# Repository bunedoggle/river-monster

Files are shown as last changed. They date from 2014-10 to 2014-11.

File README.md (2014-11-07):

river-monster
=============

River monitoring hack-a-thon at the Lowell Makerspace.

Goals:
 - Battery-less sensors using energy havevesting
 - Sensor gateway using SMS
 - Solar gateway charging

###Update: 11/6/2014

As a first pass project we're going to change the remote sensor design.  Each sensor node will use an inexpensive 433Mhz transmitter module (like this) and an Arduino pro mini.  Using the low power library we shuold be able to get month of battery life from a few AA batteries, maybe longer with a lithium-ion.

The gateway will be an Arduino Uno with a GPRS sheild, 433 Mhz reciever and a large antenna.

This will greatly simplify the design and allow us to quickly build a proof on concept that can be expanded.

See the wiki for more info. 

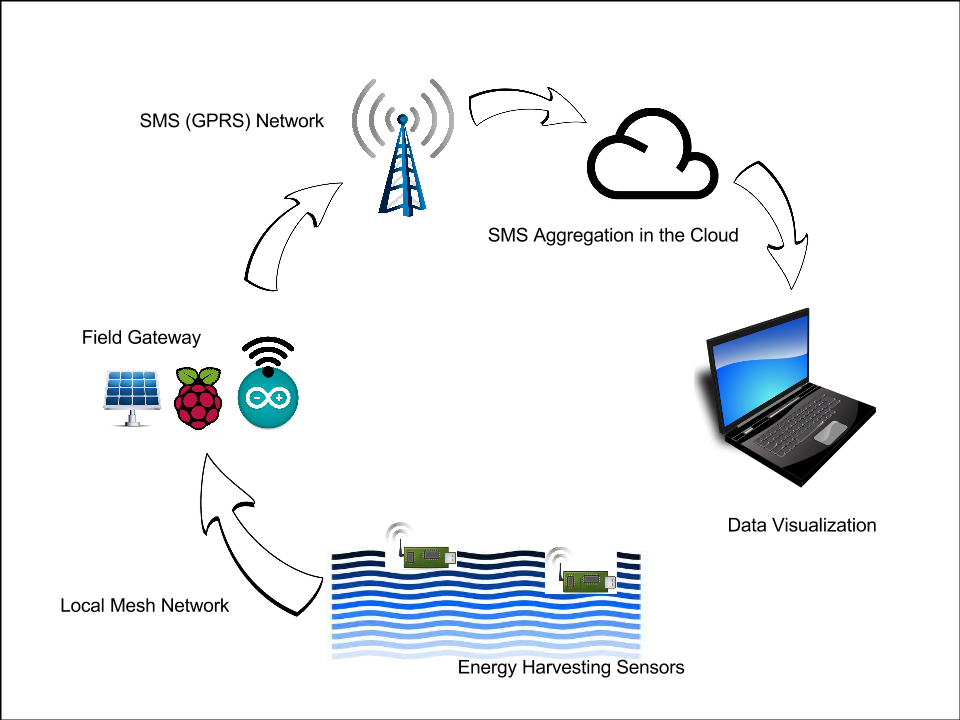
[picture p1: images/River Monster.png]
River monster block diagram


Resources:
 - http://www.seeedstudio.com/depot/GPRS-Shield-V20-p-1379.html?cPath=132_134
 - http://publiclab.org/wiki/water-quality-sensor
 - https://www.enocean.com/en/enocean-pi/

Low Power Arduino lib:
 - http://www.rocketscream.com/blog/2011/07/04/lightweight-low-power-arduino-library/
 - https://github.com/rocketscream/Low-Power

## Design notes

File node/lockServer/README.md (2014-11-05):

DEPLOYMENT

- Install node.js and MongoDB (figure it out!)

- You must have a Twilio acccount for this application to work.
  - Sign up at Twilio and obtain a phone number

- You also need a publicly accessible server for Twilio to callback to when SMS arrives
  - see ngrok.com for a way to expose localhost externally

- Login to Twilio and redirect the callback page to http://<yourserver>/api/smsMessage

There is a version currently hosted on OpenShift.  This project has all the crap
needed to make that work (they use environment vars to figure out the right
ports and address to use.  It will work locally or on OpenShift).

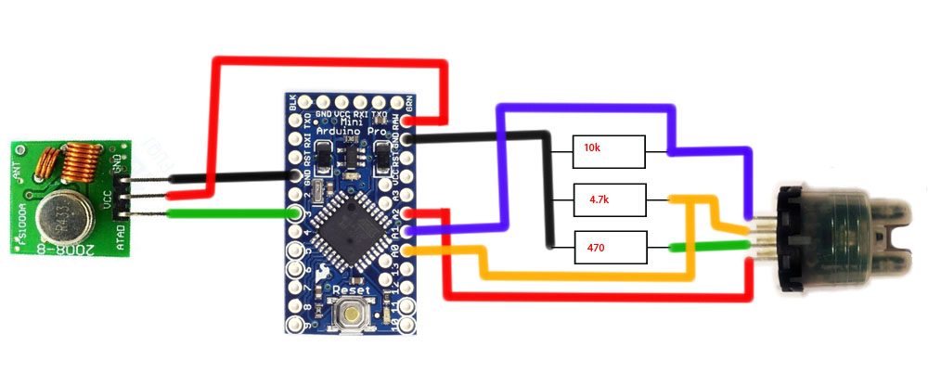
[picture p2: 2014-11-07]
images/sensor_node_rev1.jpg

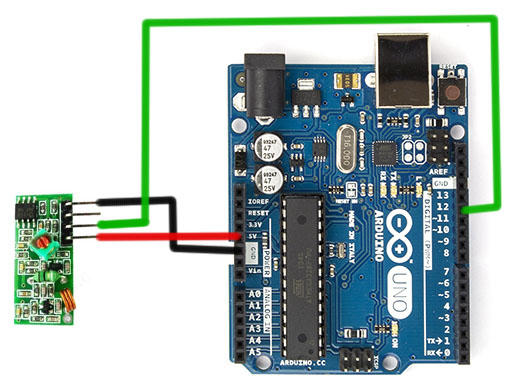
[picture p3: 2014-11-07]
images/gateway_rev1.jpg

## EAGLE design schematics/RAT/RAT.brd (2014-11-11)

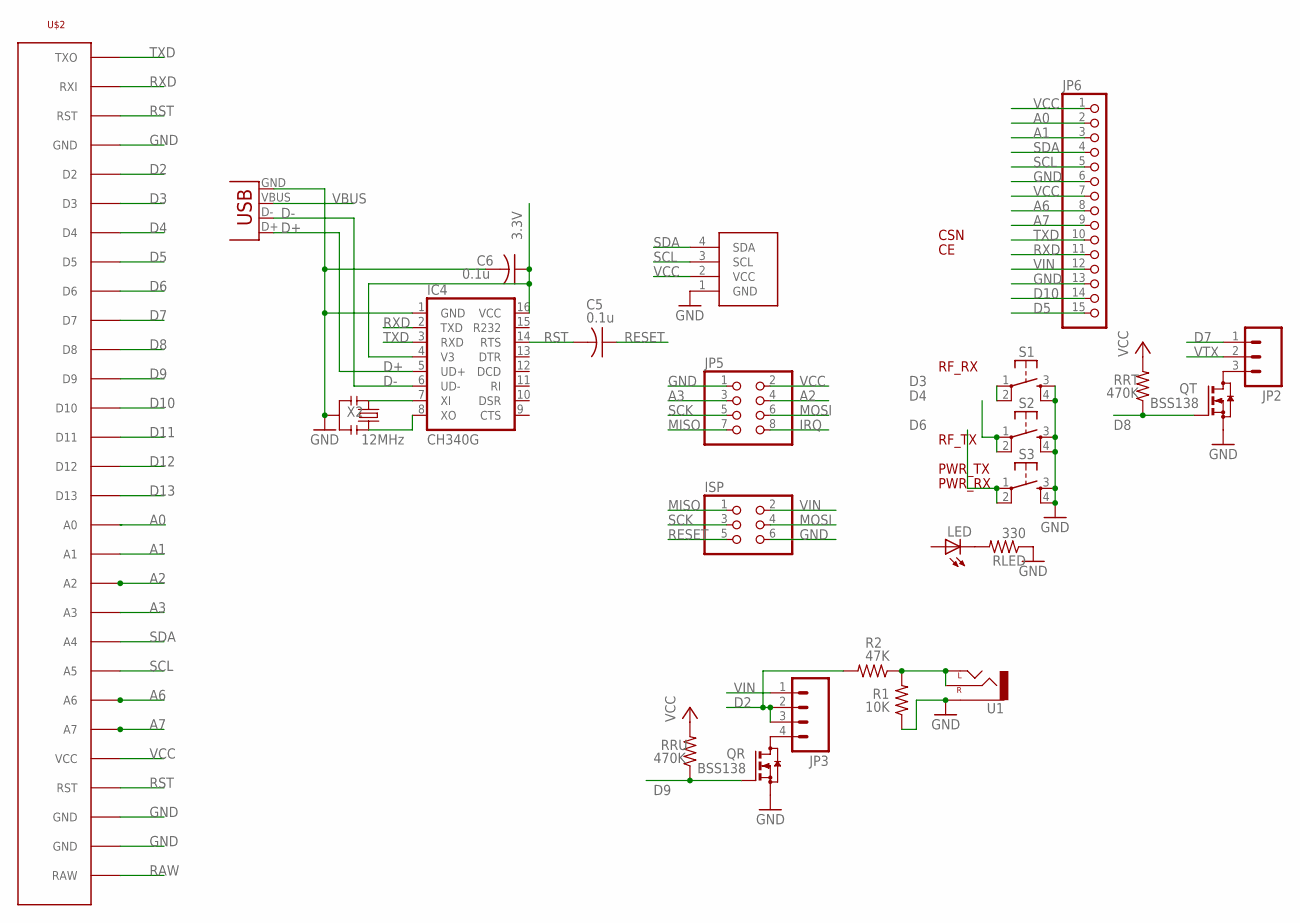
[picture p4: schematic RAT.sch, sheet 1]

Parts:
C5, C6: 0.1u; C0805K
IC4: CH340G; SO16
ISP: PINHD-2X3; 2X03
JP2: M03LOCK_LONGPADS; 1X03_LOCK_LONGPADS
JP3: M04LOCK; 1X04_LOCK
JP5: PINHD-2X4; 2X04
JP6: PINHD-1X15-CB; 1X15-CB
LED: LEDCHIPLED_0805; CHIPLED_0805
QR: BSS138; SOT23
QT: BSS138; SOT23
R1: 10K; R0805
R2: 47K; R0805
RLED: 330; R0805
RRT: 470K; R0805
RRU: 470K; R0805
S1, S2, S3: TAC_SWITCHPTH; TACTILE-PTH
U1: AUDIO-JACKPTH; AUDIO-JACK
U$1: SSD1306_OLED_I2C
U$2: ARDUINO-PRO-MINI-CORRECT; ARDUINO-PRO-MINI
X1: USBSMD; USB-MINIB
X2: 12MHz; RESONATOR-SMD

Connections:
3.3V: C6.1, IC4.4 (V3), IC4.16 (VCC)
A0: JP6.2, U$2.A0
A1: JP6.3, U$2.A1
A2: JP5.4, U$2.A2
A3: JP5.3, U$2.A3
A6: JP6.8, U$2.A6@1 (A6), U$2.A6@2 (A6)
A7: JP6.9, U$2.A7@1 (A7), U$2.A7@2 (A7)
D2: JP3.2, JP3.3, R2.2, U$2.2 (D2)
D3: S1.1, S1.2, U$2.3 (D3)
D4: S2.1, S2.2, U$2.4 (D4)
D5: JP6.15, U$2.5 (D5)
D6: S3.1, S3.2, U$2.6 (D6)
D7: JP2.1, U$2.7 (D7)
D8: QT.1 (G), RRT.1, U$2.8 (D8)
D9: QR.1 (G), RRU.1, U$2.9 (D9)
D10: JP6.14, U$2.10 (D10)
D11: U$2.11 (D11)
D12: U$2.12 (D12)
D13: U$2.13 (D13)
D+: IC4.5 (UD+), X1.D+
D-: IC4.6 (UD-), X1.D-
GND: C6.2, IC4.1 (GND), ISP.6, JP5.1, JP6.6, JP6.13, QR.2 (S), QT.2 (S), R1.1, RLED.1, S1.3, S1.4, S2.3, S2.4, S3.3, S3.4, U1.SLEEVE, U$1.1 (GND), U$2.GND@1 (GND), U$2.GND@2 (GND), U$2.GND@3 (GND), X1.GND, X2.2; also elsewhere on the board
IRQ: JP5.8
MISO: ISP.1, JP5.7
MOSI: ISP.4, JP5.6
unnamed: LED.C, RLED.2
unnamed: R1.2, R2.1, U1.RING (RIGHT), U1.TIP (LEFT)
unnamed: JP3.4, QR.3 (D)
unnamed: JP2.3, QT.3 (D)
unnamed: IC4.7 (XI), X2.1
unnamed: IC4.8 (XO), X2.3
RAW: U$2.RAW
RESET: C5.1, ISP.5
RST: C5.2, IC4.14 (RTS), U$2.RST@1 (RST), U$2.RST@2 (RST)
RXD: IC4.2 (TXD), JP6.11, U$2.RXI
SCK: ISP.3, JP5.5
SCL: JP6.5, U$1.3 (SCL), U$2.A5
SDA: JP6.4, U$1.4 (SDA), U$2.A4
TXD: IC4.3 (RXD), JP6.10, U$2.TXO
VBUS: X1.VBUS; also elsewhere on the board
VCC: JP5.2, JP6.1, JP6.7, RRT.2, RRU.2, U$1.2 (VCC), U$2.VCC; also elsewhere on the board
VIN: ISP.2, JP3.1, JP6.12
VTX: JP2.2; also elsewhere on the board

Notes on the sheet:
RF_RX
PWR_RX
PWR_TX
RF_TX
CSN

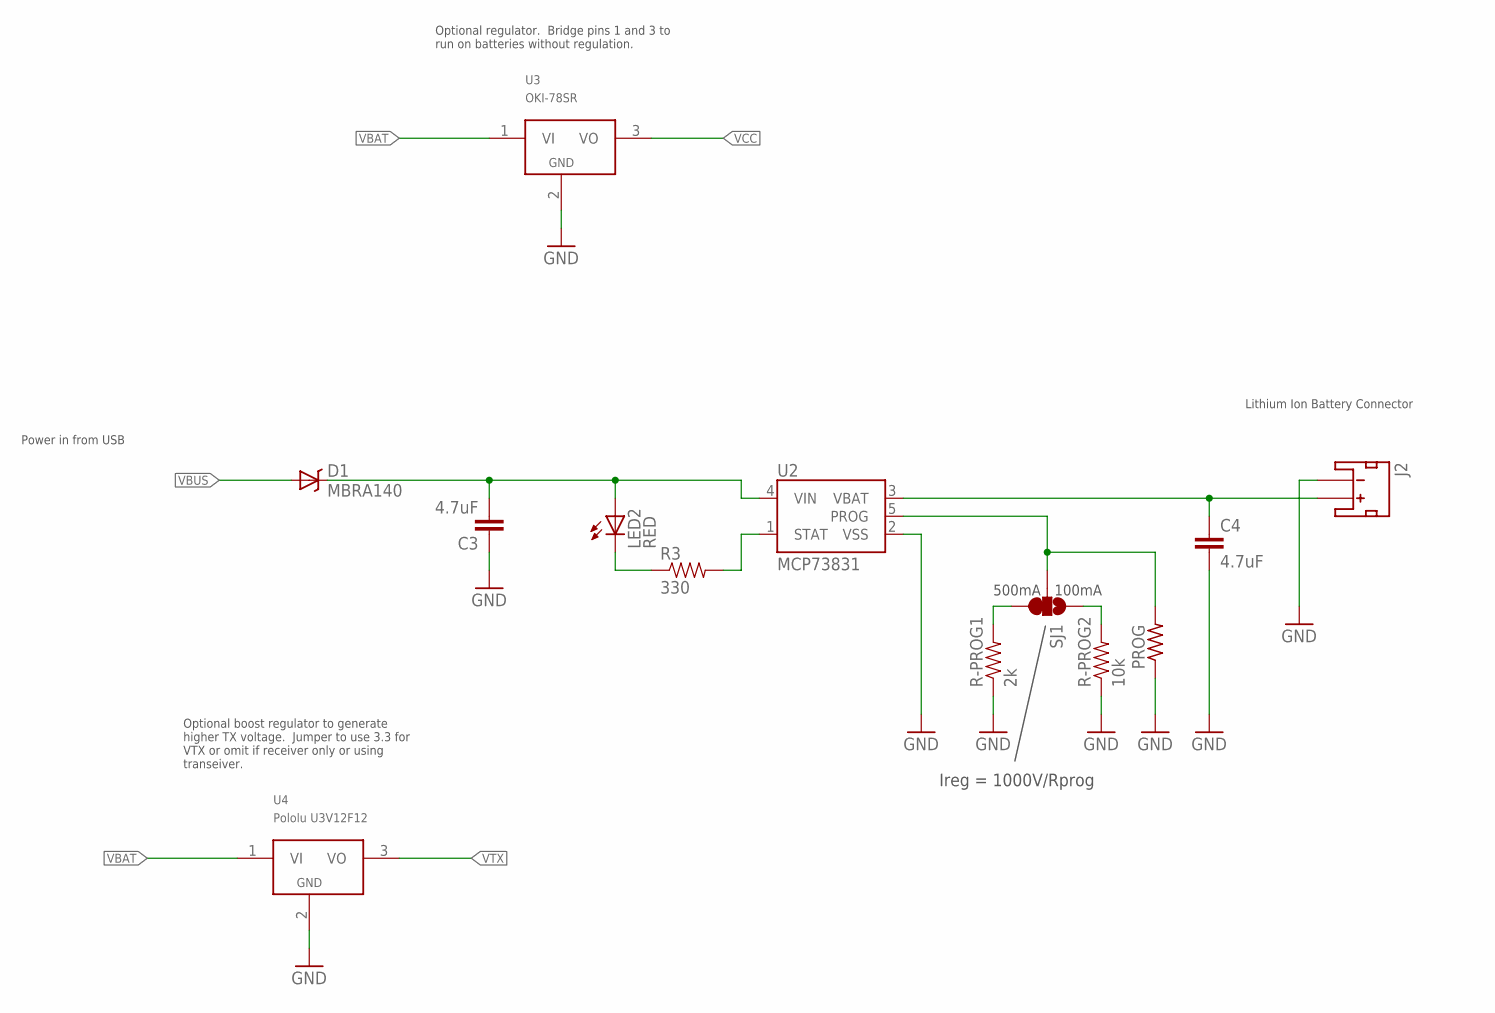
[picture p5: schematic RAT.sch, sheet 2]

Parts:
C3, C4: 4.7uF; 0603-CAP
D1: MBRA140; SMA-DIODE
J2: JST_2MM_MALE; JST-2-SMD
LED2: RED; LED-0603
PROG: R-US_R0603; R0603
R3: 330; 0603-RES
R-PROG1: 2k; 0603-RES
R-PROG2: 10k; 0603-RES
SJ1: SOLDERJUMPER_2WAYS; SJ_3
U2: MCP73831; SOT23-5
U3: OKI-78SR; TO-220
U4: Pololu U3V12F12; TO-220

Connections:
GND: C3.1, C4.2, J2.1 (-), PROG.1, R-PROG1.1, R-PROG2.1, U2.2 (VSS), U3.2 (GND), U4.2 (GND); also elsewhere on the board
unnamed: R-PROG1.2, SJ1.3
unnamed: R3.2, U2.1 (STAT)
unnamed: R-PROG2.2, SJ1.1
unnamed: LED2.C, R3.1
PROG: PROG.2, SJ1.2, U2.5 (PROG)
VBAT: C4.1, J2.2 (+), U2.3 (VBAT), U3.1 (VI), U4.1 (VI)
VBUS: D1.A; also elsewhere on the board
VBUS_DIODE: C3.2, D1.C, LED2.A, U2.4 (VIN)
VCC: U3.3 (VO); also elsewhere on the board
VTX: U4.3 (VO); also elsewhere on the board

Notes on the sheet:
500mA
100mA
Ireg = 1000V/Rprog
Optional regulator. Bridge pins 1 and 3 to run on batteries without regulation.
Lithium Ion Battery Connector
Power in from USB
Optional boost regulator to generate higher TX voltage. Jumper to use 3.3 for VTX or omit if receiver only or using transeiver.

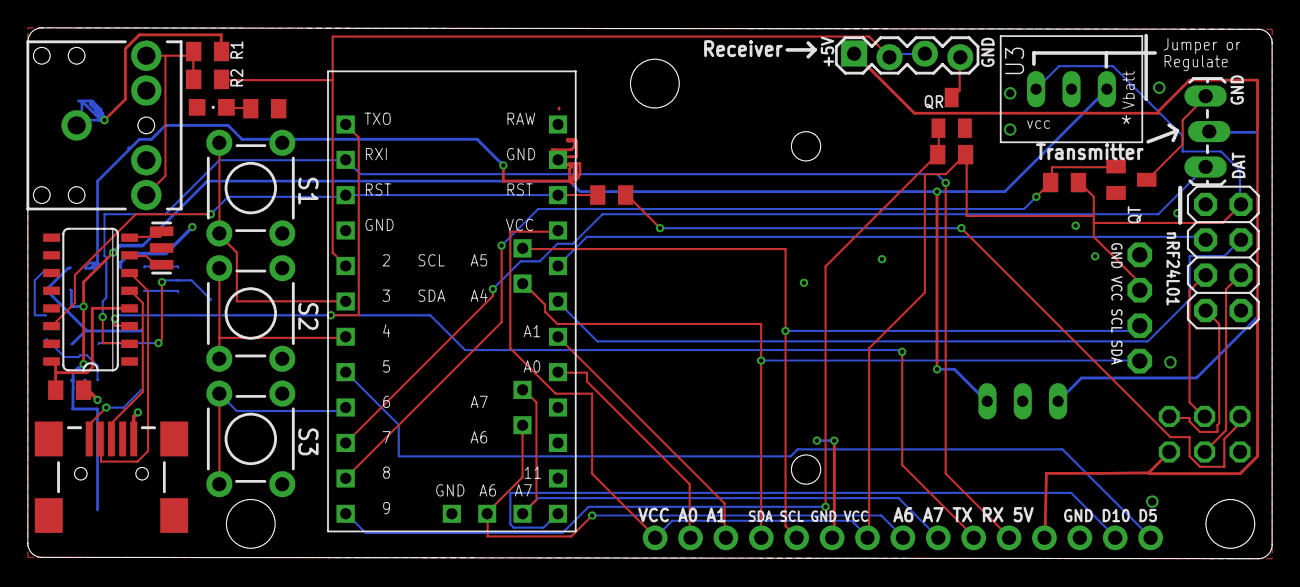
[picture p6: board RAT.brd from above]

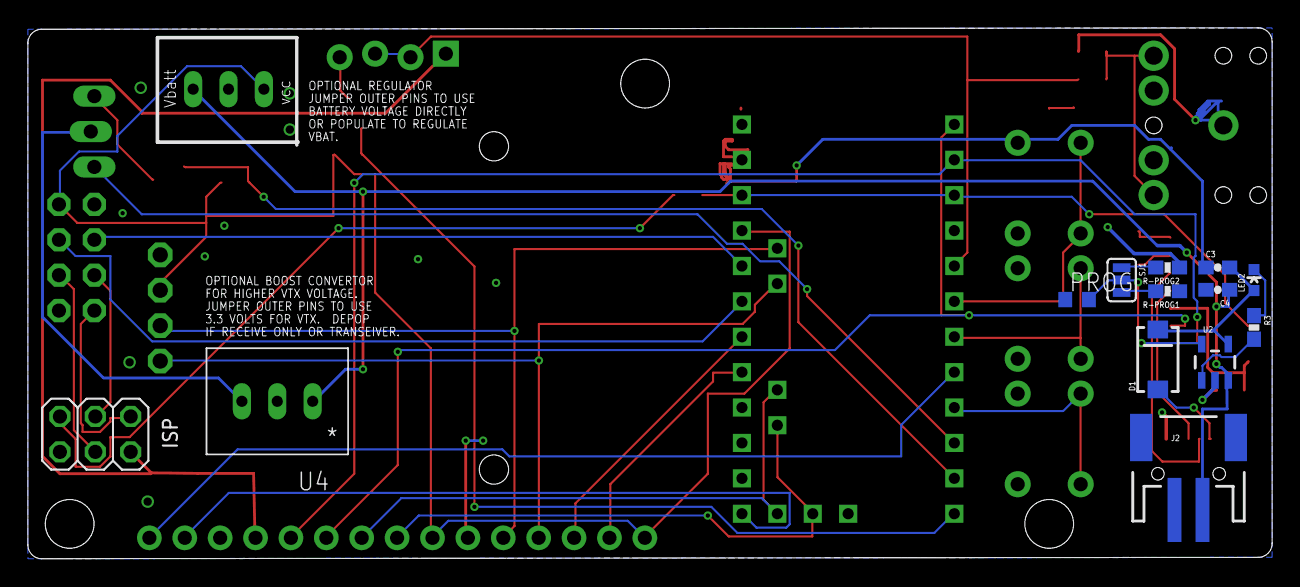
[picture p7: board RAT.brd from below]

Board: 2 copper layers, 89.3 x 38.1 mm, 37 parts (13 on the bottom side), 45 nets.

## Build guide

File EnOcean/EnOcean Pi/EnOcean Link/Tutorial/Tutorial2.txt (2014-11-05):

_EOLINK_SAVE
HEADER
{
 name:_HUMAN_ARCHIVE
 major:0x0
 minor:0x2
}
Gateway
{
 myDeviceManager
 {
  Counter:0x1
  Device_0000
  {
   profile
   {
    rorg:0xa5
    func:0x2
    type:0x5
    manufacturer:0x7ff
   }
   dBm:0x0
   ID:0x100867a
   secIn
   {
   }
   secIn
   {
   }
  }
 }
 myFilter
 {
  type:0x1
  Counter:0x1
  ID_0000:0x100867a
 }
 myLearnFilter
 {
  type:0x2
  maxdBm:0x0
  mindBm:0xffffff81
 }
 LearnMode:FALSE
}

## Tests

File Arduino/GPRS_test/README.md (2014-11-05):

#### To use this test:
- Remove GPRS shield and program Arduino.  
- Power off Arduino and attach GPRS shield
- Power on and attach serial port at 19200
- Enter 't' and the Arduino will send a text to the number in the code

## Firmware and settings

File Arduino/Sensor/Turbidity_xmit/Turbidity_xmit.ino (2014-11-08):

#include <LowPower.h>
#include <RH_ASK.h>
#include <SPI.h> // Not actually used but needed to compile

#define UID 0

//RH_ASK::RH_ASK(uint16_t speed, uint8_t rxPin, uint8_t txPin, uint8_t pttPin, bool pttInverted)
RH_ASK driver( 1200, 2, 3, 4, 5 );

typedef struct __attribute__((packed)){
	uint8_t id;
	uint32_t time;
	uint16_t temperature;
	uint16_t turbidity;	
	} PACKET_T;

PACKET_T data;
	
void setup()
{
	Serial.begin(9600);	  // Debugging only
	if (!driver.init() )
	Serial.println("init failed");
	data.time = 0;
	
	// Using this pin to power the turbidity sensor
	pinMode(A2,OUTPUT);
	digitalWrite(A2,HIGH);
	
	//analogReference(INTERNAL);
}

void loop()
{	
	// Turn on sensor
	digitalWrite(A2,HIGH);
	
	// Let the sensor settle
	delay(50);
	
	// Read sensor and build packet
	data.id = UID;
	data.time += 1;
	data.temperature = analogRead(A1);   
	data.turbidity = analogRead(A0);     

	//Serial.print("XMIT");
	//Serial.println(data.time);

	//Serial.print("Turb:");
	//Serial.print(analogRead(A0));
	//driver.printBuffer()

	// Turn off sensor while xmit
	digitalWrite(A2,LOW);

	// Send data
	driver.send((uint8_t*)&data,sizeof(data));
	driver.waitPacketSent();
	
	// Sleep (most power)
	//delay(1000);

	// Low power sleep (less power)
	//LowPower.idle(SLEEP_1S, ADC_OFF, TIMER2_OFF, TIMER1_OFF, TIMER0_OFF, SPI_OFF, USART0_OFF, TWI_OFF);
	
	// Deep powerdown (least power)
	longPowerDown(60); // in Seconds 
}

// Most power efficient in multiples of 8 seconds
void longPowerDown(int seconds){
	int i;
	
	for(i=0; i<(seconds/8); i++){
		LowPower.powerDown(SLEEP_8S, ADC_OFF, BOD_OFF);
	}
	
	for(i=0;i<(seconds%8); i++){
		LowPower.powerDown(SLEEP_1S, ADC_OFF, BOD_OFF);
	}
}

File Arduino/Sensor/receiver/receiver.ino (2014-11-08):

// Turbidity chart
// fluid              reading   voltage
//------------------------------------------
// water	        924	2.95
// milk	                19	0.065

// Temperature Chart
// Deg                reading   voltage
// 34                  266
// 44                  315
// 78                  525
// 145                 800

#include <RH_ASK.h>
#include <SPI.h> // Not actualy used but needed to compile

//RH_ASK::RH_ASK(uint16_t speed, uint8_t rxPin, uint8_t txPin, uint8_t pttPin, bool pttInverted)
RH_ASK driver( 1200, 12, 3, 4, 5 );

typedef struct __attribute__((packed)){
	uint8_t id;
	uint32_t time;
	uint16_t temperature;
	uint16_t turbidity;
	} PACKET_T;

PACKET_T data;
PACKET_T* dataPtr;

// nodes for linear equations / nodepoits are concatening  lines
float tempPoints[5][2]= {
  {
    266,34  }
  , {
    315,44  }
  , {
    413,65  }
  , {
    523,78  }
  ,{
    800,145  }
};

float turbPoints[4][2]= {
  {
    18,4000  }
  , {
    155,1500  }
  , {
    915,10  }
  , {
    1023, 0 }
};



void setup()
{  
  Serial.begin(9600);	// Debugging only
  if (!driver.init())
       Serial.println("init failed");
}

void loop()
{
    uint8_t buf[RH_ASK_MAX_MESSAGE_LEN];
    uint8_t buflen = sizeof(buf);

    if (driver.recv(buf, &buflen)) // Non-blocking
    {
	// Message with a good checksum received, dump it.
	driver.printBuffer("Raw Packet:", buf, buflen);
        
        dataPtr = (PACKET_T*) buf;
       	Serial.print("Device ID:");
	Serial.println(dataPtr->id);
                
       	Serial.print("  Packet num:");
	Serial.println(dataPtr->time);
               
       	Serial.print("  Temp:(raw:");
        Serial.print(dataPtr->temperature);
        Serial.print("): ");
	Serial.println(reMap(tempPoints, dataPtr->temperature));
        
	Serial.print("  Turb:(raw:");
        Serial.print(dataPtr->turbidity);
        Serial.print("): ");
	Serial.println(reMap(turbPoints, dataPtr->turbidity));
    }
}


//***************************************************************************
//
int reMap(float pts[10][2], int input) {
  int rr;
  float bb,mm;

  for (int nn=0; nn < 4; nn++) {

    if (input >= pts[nn][0] && input <= pts[nn+1][0]) {
      mm= ( pts[nn][1] - pts[nn+1][1] ) / ( pts[nn][0] - pts[nn+1][0] );
      mm= mm * (input-pts[nn][0]);
      mm = mm +  pts[nn][1];
      rr = mm;
    }
  }
  return(rr);
}

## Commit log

2014-10-28 Added low power arduino lib link
2014-10-28 Added Raspberry pi schematic to docs
2014-10-28 Added serial port example driver code
2014-10-29 Pushing the STM 33X temp sensor users manual
2014-10-30 Added working Arduino GPRS shield example
2014-11-05 Pushing a working xmit/rcv example that connects two arduinos via cheap 433mhz modules
2014-11-05 Working transmitter, sleeps, 5.15 mA draw at idle. Measurements still a bit wonky
2014-11-07 Receive code now reading faily close turbidity and temperature values. Added attribute packed to data packet so it works.
    [Turbidity_xmit.ino, receiver.ino]
2014-11-07 added wireing for sensor node
2014-11-07 added wireing for gateway
2014-11-08 Added time to low poer sleep. Power down sensor during xmit. Better calibration on recvr.
2014-11-11 Adding schematic and board layout. This was a first pass. I'm about to unroute the board and move all the components. this is a checkpoint
    [RAT.brd, RAT.sch]

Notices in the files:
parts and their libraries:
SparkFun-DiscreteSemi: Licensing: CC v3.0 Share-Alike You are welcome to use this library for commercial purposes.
